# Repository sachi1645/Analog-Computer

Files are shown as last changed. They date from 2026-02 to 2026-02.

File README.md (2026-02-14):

# Analog Computer Project - Team Hypertronics

## 📖 Overview
**Team Hypertronics** developed this project for the **EN2091 - Laboratory Practice and Projects** module. It demonstrates the functionality of operational amplifier (op-amp) circuits in performing fundamental analog computations. The system is designed to process signals within the **1 Hz to 10 kHz** frequency range.

The analog computer features a dual-channel input interface, adjustable gain control mechanisms, and a modular, stable power supply system.

---

## 🧮 Key Functionalities
The device performs the following mathematical operations using analog circuitry:
* **Addition**
* **Subtraction**
* **Multiplication**
* **Integration**
* **Differentiation**

---

## 🛠 Technical Specifications
The device parameters achieved during the final implementation are as follows:

| Parameter | Value |
| :--- | :--- |
| **Supply Voltage** | $\pm 12V$ (Recommended), Max $\pm 18V$ |
| **Bandwidth** | $1\text{ kHz} - 10\text{ kHz}$ |
| **Input Current** | Max $10\text{ mA}$ |
| **Output Voltage** | $\pm 12V$ |
| **Maximum Noise Level** | $100\text{ mV}$ |
| **Accuracy** | $\pm (1-10)\%$ |
| **Maximum Gain** | x10 |

---

## 🔌 Circuit Design & Components

### Component Selection
* **Op-Amp (UA741):** Selected for its affordability and stability. The ~1 MHz bandwidth is sufficient for the project's target signal range.
* **Resistors (1 kΩ):** * Chosen over smaller values (e.g., $100\Omega$) to reduce current draw and power consumption.
    * Chosen over larger values (e.g., $100\text{ k}\Omega$) to prevent filtering of the input signal and bandwidth reduction.
* **Diodes:**
    * **1N4148:** Used for small signals due to low junction capacitance, fast switching, and thermal stability.
    * **1N4007:** Used in the power supply rectifier for its high Peak Reverse Voltage ($1000V$) and 1A current handling.

### Mathematical Modules
1.  **Adder & Subtractor:** Implemented using standard inverting op-amp configurations with $1\text{ k}\Omega$ resistors for optimal bandwidth/power balance.
2.  **Multiplier (Log-Antilog):**
    * **Issue:** Initially attempted using a Gilbert Cell, but mismatches in BJTs caused non-linear behavior.
    * **Solution:** Replaced with a Log-Antilog multiplier circuit using diodes and op-amps. This improved linearity and generated the correct mathematical output ($V_{out} = V_1 \cdot V_2$).
    * **Design Note:** Larger input resistors were used here to ensure small currents for a predictable log function.
3.  **Power Supply:** A dedicated module providing a fixed $\pm 12V$ using **LM7812** and **LM7912** voltage regulators.

---

## 💻 Simulation & Tools
The project utilized a combination of simulation software and hardware implementation:
* **Simulink:** Used for initial block-level simulation and verifying mathematical logic.
* **LTSpice:** Used for circuit-level simulation.
* **PCB Design:** Custom PCBs designed for the computing modules and power supply.

---

## ⚠️ Challenges & Solutions
* **Challenge:** Non-linearity in the multiplier circuit due to BJT mismatches in the Gilbert cell architecture.
* **Solution:** Transitioned to a **Log-Antilog multiplier** design with specific modifications, which successfully linearized the output.

---

## 👥 Team Hypertronics
* **Wijesinghe U.G.S.K.D:** Simulation, Component Selection, PCB Schematic Design
* **Dilhara D.S:** PCB Design, Breadboard Implementation
* **Wijesekara W.A.G.S:** Power Supply Design, Soldering
* **Upekshani T.S:** Enclosure Design, Breadboard Implementation

---
*University of Moratuwa - Dept. of Electronic & Telecommunication Engineering*

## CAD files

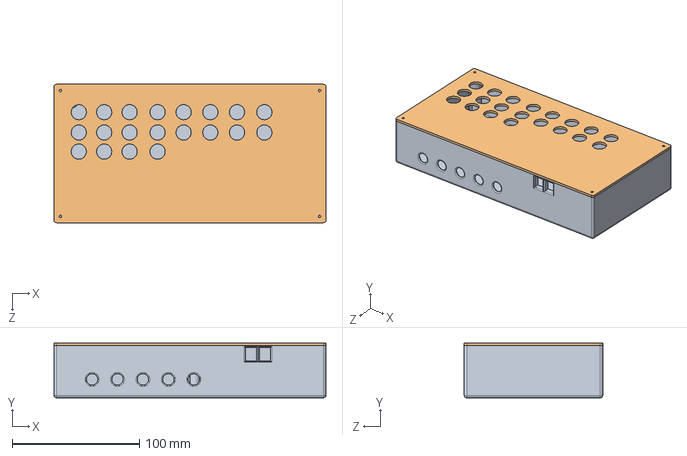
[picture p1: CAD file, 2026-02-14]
Enclosure_Design/Analog_Computer/Analog Computer Main.SLDASM
214.0 x 43.0 x 109.0 mm
bottom-main
top-main

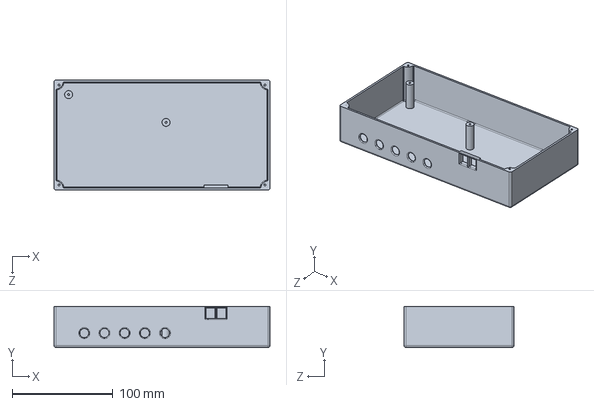
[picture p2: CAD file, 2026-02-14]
Enclosure_Design/Analog_Computer/Bottom-main.SLDPRT
214.0 x 41.0 x 109.0 mm

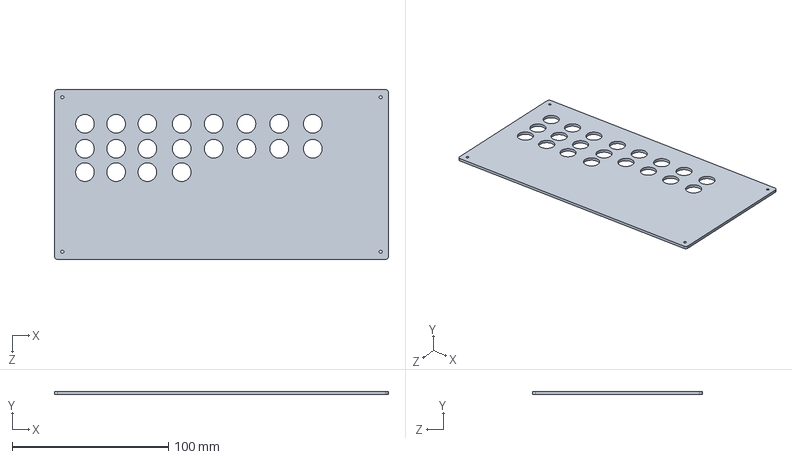
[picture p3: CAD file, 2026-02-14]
Enclosure_Design/Analog_Computer/top-main.SLDPRT
214.0 x 2.00 x 109.0 mm

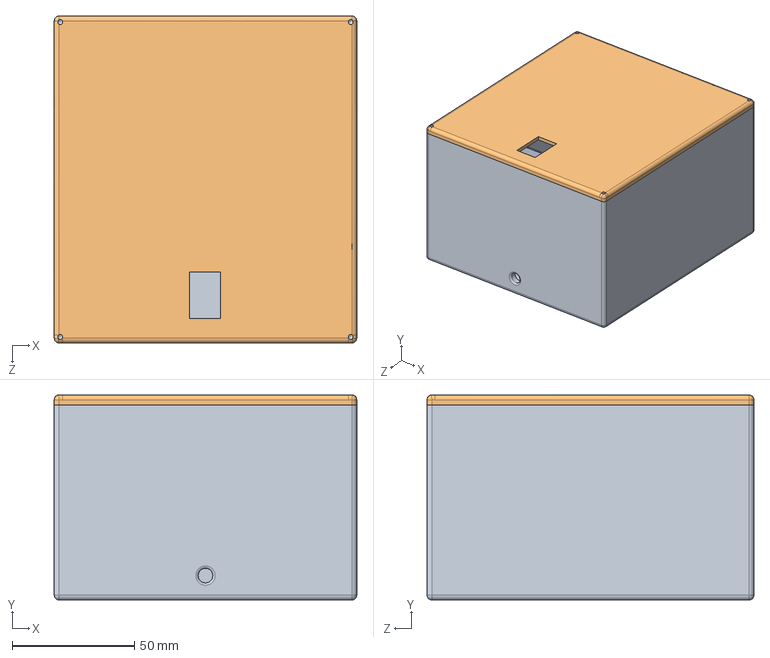
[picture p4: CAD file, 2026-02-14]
Enclosure_Design/Power_Supply/Analog Computer Power Supply.SLDASM
124.0 x 84.0 x 134.0 mm
bottom-powersupply
top-powersupply

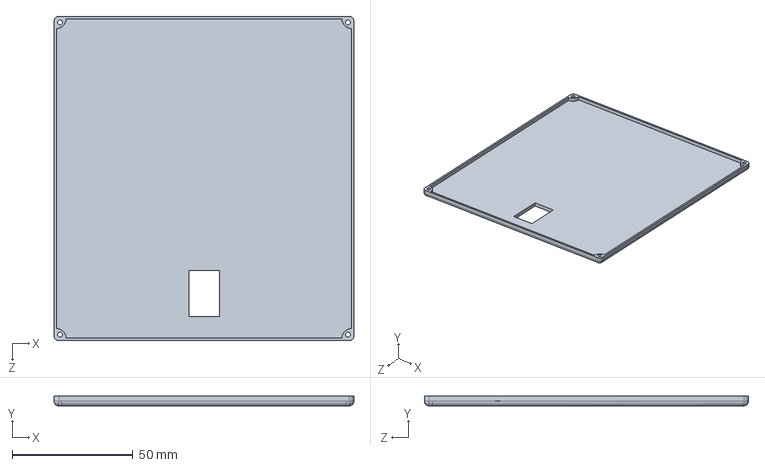
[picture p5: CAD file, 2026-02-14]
Enclosure_Design/Power_Supply/top-powersupply.SLDPRT
124.0 x 4.00 x 134.0 mm

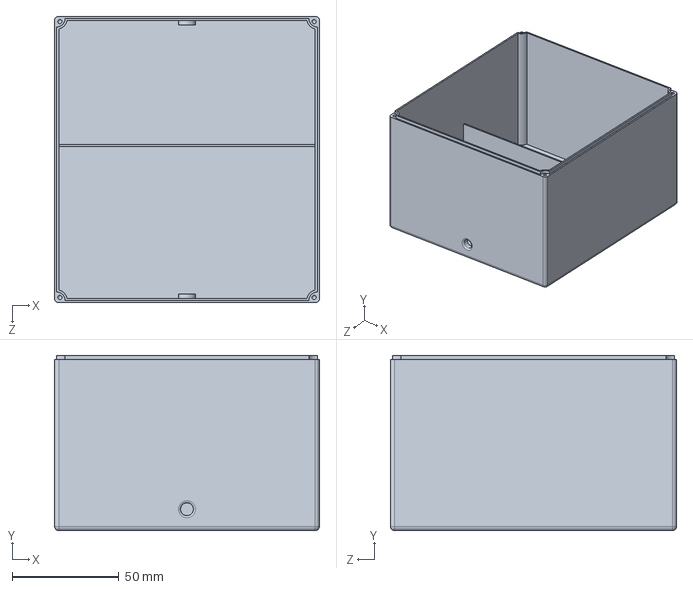
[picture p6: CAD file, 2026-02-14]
Enclosure_Design/Power_Supply/bottom-powersupply.SLDPRT
124.0 x 82.0 x 134.0 mm

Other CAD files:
Enclosure_Design/Analog_Computer/Bottom-main.STL
Enclosure_Design/Analog_Computer/top-main.STL
Enclosure_Design/Power_Supply/bottom-powersupply.STL
Enclosure_Design/Power_Supply/top-powersupply.STL

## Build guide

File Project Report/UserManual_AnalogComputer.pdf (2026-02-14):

# ANALOG

2024 - 2025

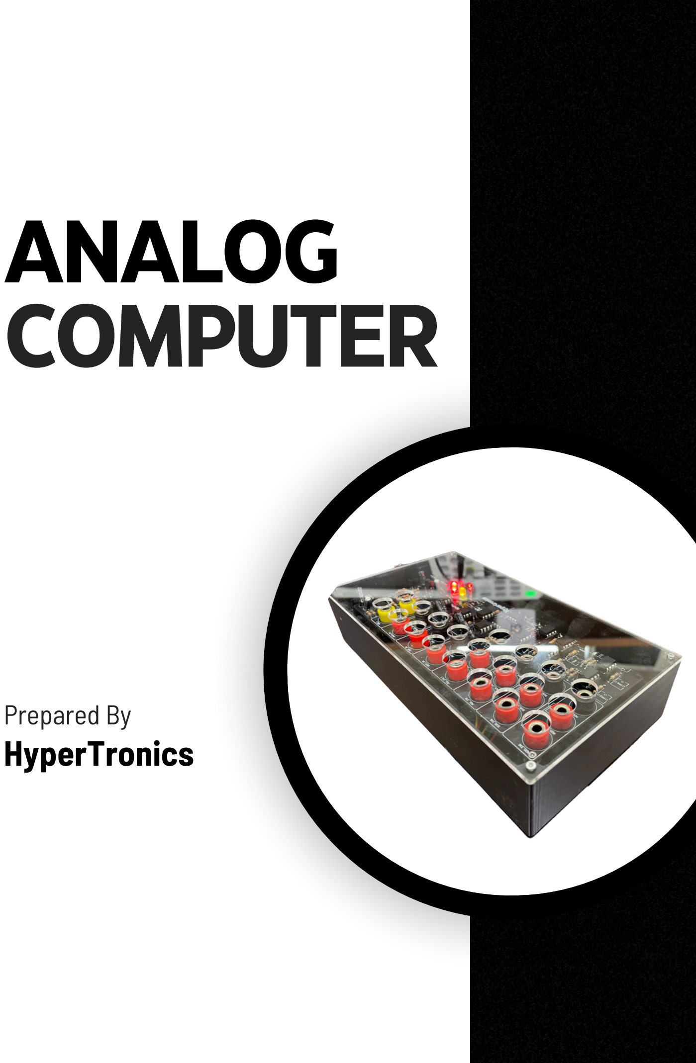
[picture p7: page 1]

# HyperTronics

# COMPUTER

# Prepared By

Before operating theAnalog Computer:
Ensure the power supply is connected properly (±12 V regulated). Do not exceed input voltage ±10 V.
Avoid short-circuiting the outputterminals.
Use only shielded cables for clean operation.
Do not operate with wet hands or near water.
Turn OFF power before changing internal wiring or PCB connections.

## USER MANUAL – ANALOG COMPUTER

### 1. Introduction

TheAnalog Computer developed by Team HyperTronics is a modular device that performs realtime analog computations using operational amplifiers.
This unit supports:
Addition
Subtraction
Multiplication
Integration
Differentiation
Adjustable Gain Control

It operates in the frequency range of 1 Hz to 10 kHz and is powered by a dedicated dual ±12 V lownoise supply module.

### 2. Safety Instructions

### 3. System Overview

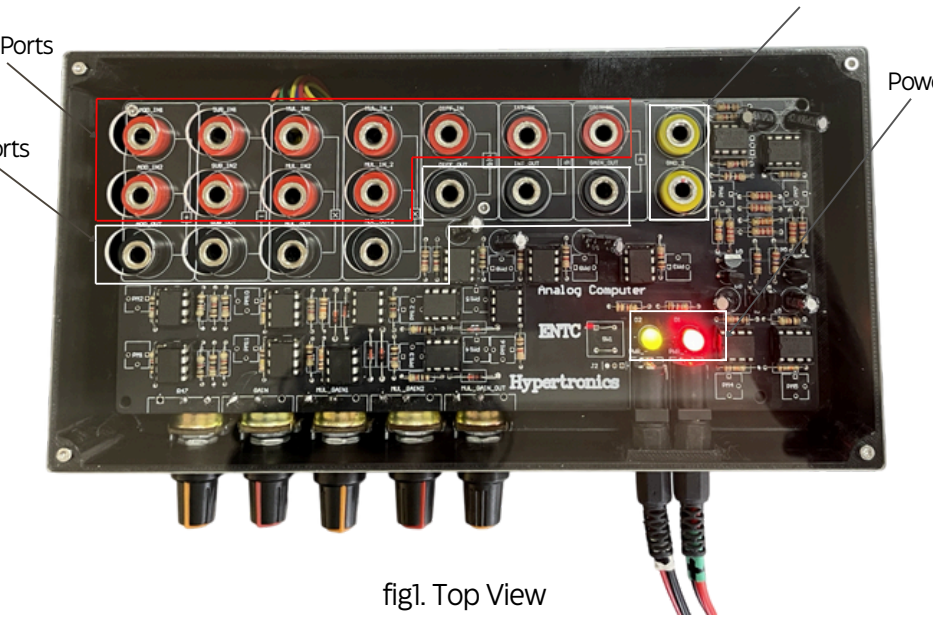
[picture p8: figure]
fig1. Top View

Input Ports

Output Ports

Ground Terminals

Power Indicator LED

1

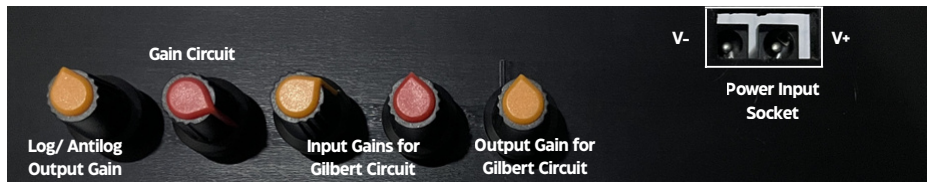
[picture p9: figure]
Log/ Antilog Output Gain; Gain Circuit; Input Gains for Gilbert Circuit; Output Gain for Gilbert Circuit; Power Input Socket

How to Use:
1.Selectthe ports forthe relevant mode. (See the symbol in PCB for select operation) 2.Input signals to Input1 and Input 2. (Red colour ports)
3.Read the result at Output. (Black colour port)

Operation Selection

1.Connectthe power supply module toAC mains.
2.Connectthe ±12 V output ofthe power module to theAnalog Computer power port. 3.Ensure correct polarity:
+12 V → V+
−12 V → V−
GND → Ground Terminal shown in fig. 1
4.Turn ON the power supply;the LED on the unit should light up.

fig2. Front View

### 3. Powering the Device

### 5. Operating Instructions

### 7. Troubleshooting

No Output
Check power supply connections.
Verify input cables and function generator output.

Distorted Output
Inputfrequency may be too high.
Component saturation; reduce input amplitude. Check gain setting.

Noise in Signals
Ensure grounding is proper.
Keep analog computer away from switching power supplies.

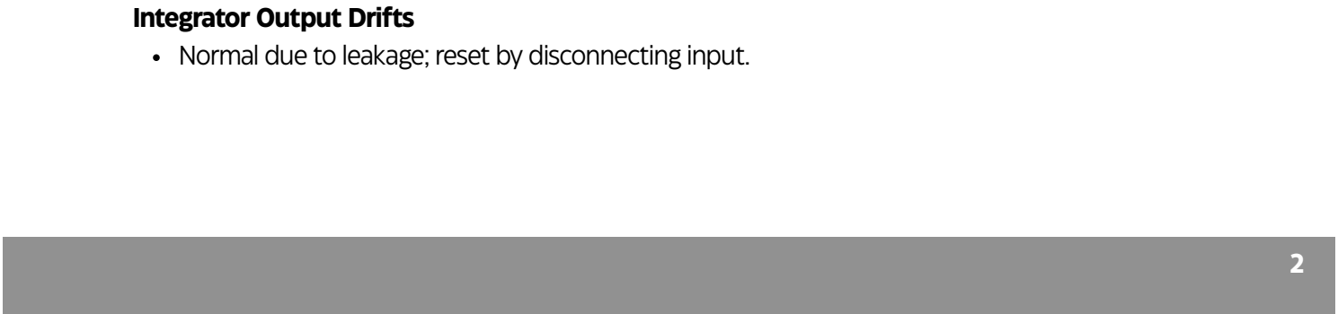
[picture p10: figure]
Integrator Output Drifts

Normal due to leakage; reset by disconnecting input.

fig3. LED indicators

fig4. Operation Selection

Parameter | Value
Supply Voltage | ±12 V
Input Range | less than 15 V
Output Range | ±12 V (approx.)
Bandwidth | 10–30 kHz
Accuracy | 1% (typical)
Weight | 600 g
Dimensions | 44 × 109 × 214 mm

### 8. Maintenance

Keep the device clean and dust-free.
Store in a dry environment.
Periodically check connectors and potentiometers.

### 9. Technical Specifications

### 10. Support

Fortroubleshooting, contactthe Team HyperTronics

3
